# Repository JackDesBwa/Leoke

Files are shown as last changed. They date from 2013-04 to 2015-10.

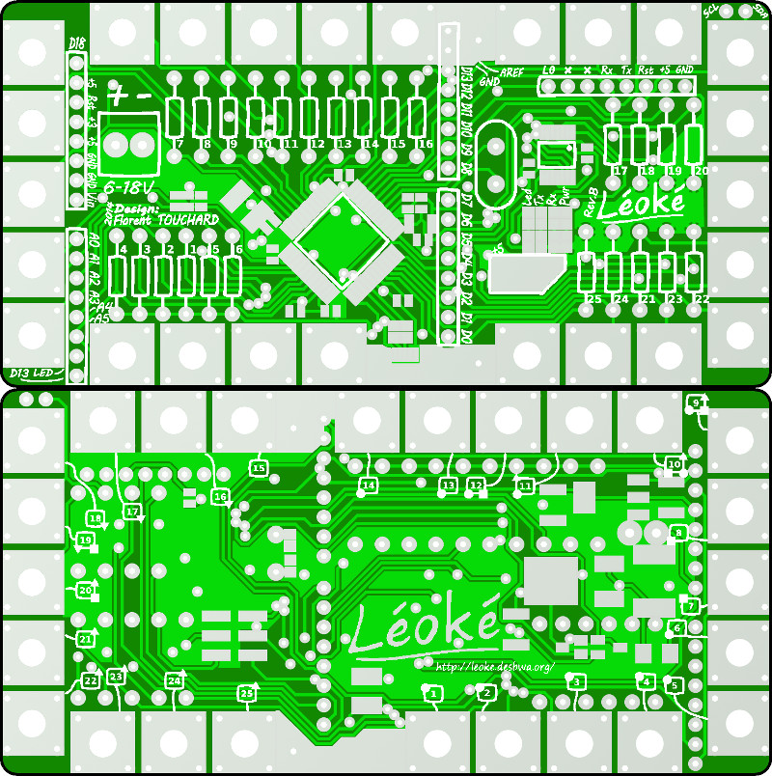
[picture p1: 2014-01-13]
webpage/carte_leoke.jpg

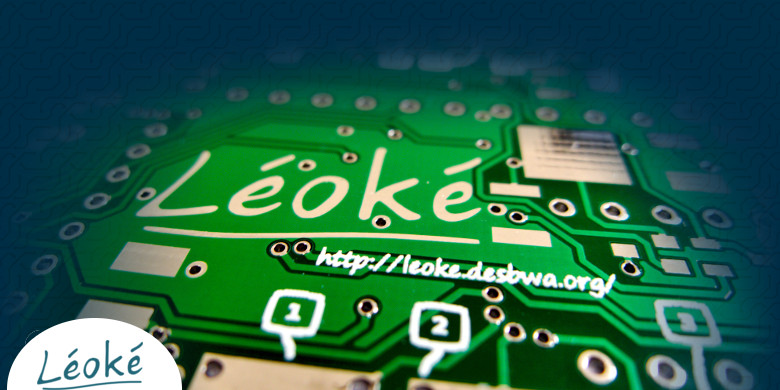
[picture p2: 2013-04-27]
webpage/head.jpg

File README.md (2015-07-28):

Léoké
=====

Please visit http://leoke.desbwa.org/ [FR] for more information.

Directory organization:

 - arduino  : Arduino-related software (Léoké Windows driver, board description & co)
 - board    : Documents about the board such as schematics or implantation
 - drawings : Miscellaneous drawings needed to make kicad files or webpage
 - gerbers  : Production files, ready to be sent to manufacturer
 - kicad    : Editable files from kicad software
 - webpage  : Files seen at above web address

Warning: This was built with arduino 1.0.6, do not know how to use it with newer versions

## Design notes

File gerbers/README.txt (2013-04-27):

leoke.gbl: Bottom coper layer
leoke.gbo: Bottom silkscreen
leoke.gbs: Bottom mask
leoke.gtl: Top copper layer
leoke.gto: Top silkscreen
leoke.gts: Top mask
leoke.drl: Drill
leoke.gko: Outline

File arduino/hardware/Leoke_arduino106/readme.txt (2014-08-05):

--------------------------------------------------------------
| Léoké Arduino Addon (based on MakeyMakey sparkfun version) |
--------------------------------------------------------------

This Arduino addon for Léoké creates an Arduino Board menu option for Léoké.

-------------------------------------------------
|         Installing the Arduino Addon          |
-------------------------------------------------

To install this addon, add "Leoke" folder into a "hardware" folder withing your Arduino sketchbook. If you don't know where your sketchbook is located, you can find it's location by going to File > Preferences within Arduino.

For Windows XP users, the sketchbook is usually located in your "My Documents/Arduino" directory. So once installed, this readme should reside in "My Documents/Arduino/hardware/Leoke". Windows 7, by default, is something like: C:\Users\<user name>\Arduino\hardware\Leoke.

Once installed, close any Arduino windows and reopen. The following board should be listed in the Tools > Board menu now:
Léoké.

-------------------------------------------------
|     Installing the Drivers (Windows only)     |
-------------------------------------------------

Windows users will need to install drivers the first time you connect Léoké. Usually a New Hardware Wizard will pop up, you'll need to direct it to the included "Drivers" folder. The driver is "Leoke.inf".

The included driver should work for Léoké with the Sparkfun VID/PID: 0x1B4F/0x2B74 (bootloader) and 0x2B75 (sketch)).

-------------------------------------------------
|            What files are included?           |
-------------------------------------------------

This addon should work with no need to modify files. If you're curious what we've done to the default Arduino files though, read on...

* bootloaders/caterina: This is a slightly modified version of the Caterina bootloader, which is used in the Arduino Leonardo. Defines were modified so the VID and PID were set to SparkFun-specific values (VID: 0x1B4F, PIDs: 0xF100/F101 [get it?!]). To compile this, you'll need to download LUFA, and point the makefile to that directory.

To compile the bootloader for Léoké, you must first set F_CPU and PID near the top of the makefile. F_CPU should be 16000000. PID should be 2B74.

This directory also includes caterina-makeymakey.hex which is the compiled images of the MaKey MaKey's bootloader. It won't be deleted after running a 'make clean'.

* cores/arduino: This is a mostly unchanged listing of all the core files required by Léoké to compile under Arduino. The files with changes are:
	USBCore.cpp: added conditional statement for seting PLLCSR.
	
* variants/leoke: This is mostly identical to the Leonardo pins_arduino.h. RX and TX macros are adapted and Léoké specific names (L1, L2...) are defined.

* boards.txt: This file is what Arduino looks at when populating its Tools > Board menu.
The "Léoké" will be added to the Tools > Board menu.

This also defines a few variables such as clock frequency, USB VID and PID, fuses, and bootloader location.

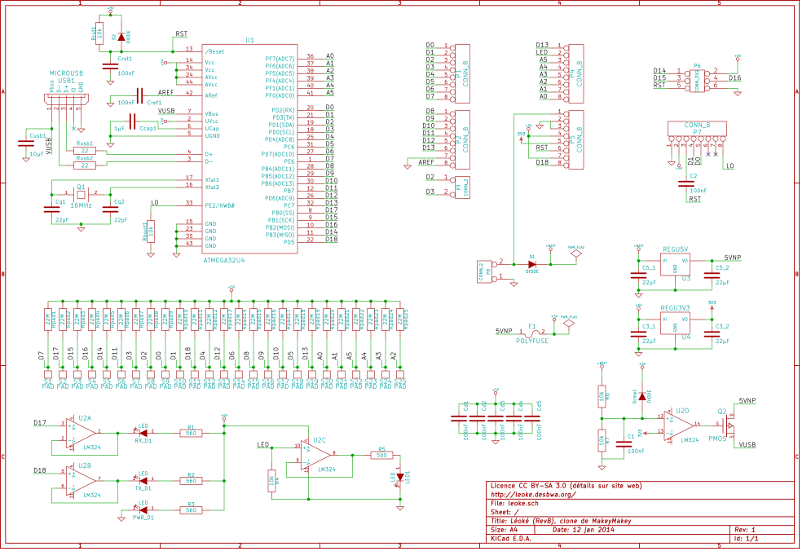
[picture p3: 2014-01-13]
webpage/schematics.png

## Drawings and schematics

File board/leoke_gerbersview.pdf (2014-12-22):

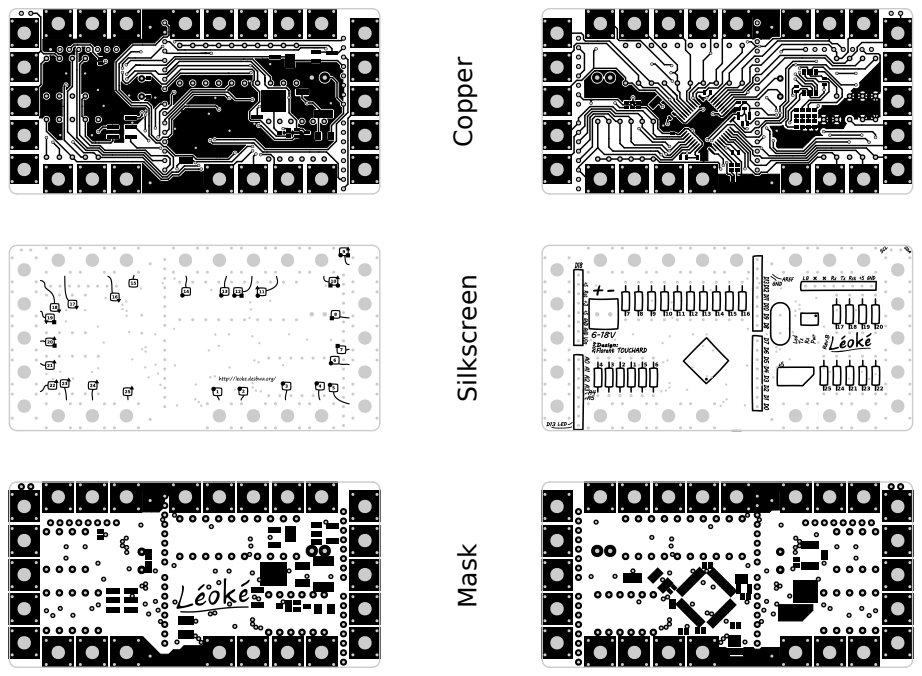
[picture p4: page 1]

Mask Silkscreen Copper

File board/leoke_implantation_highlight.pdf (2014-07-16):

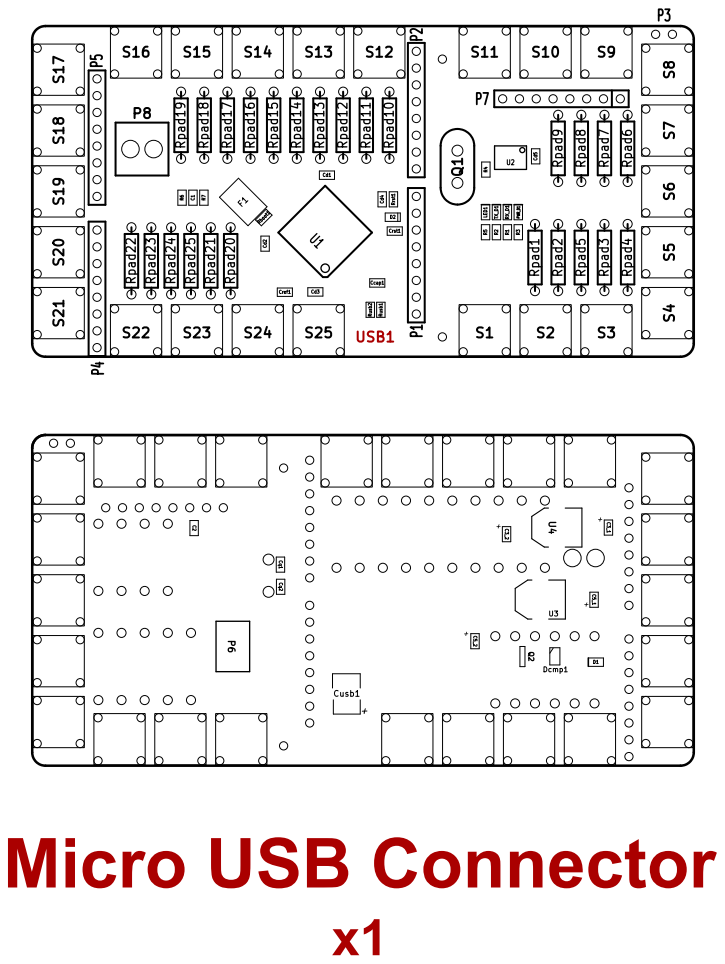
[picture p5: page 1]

Micro USB Connector

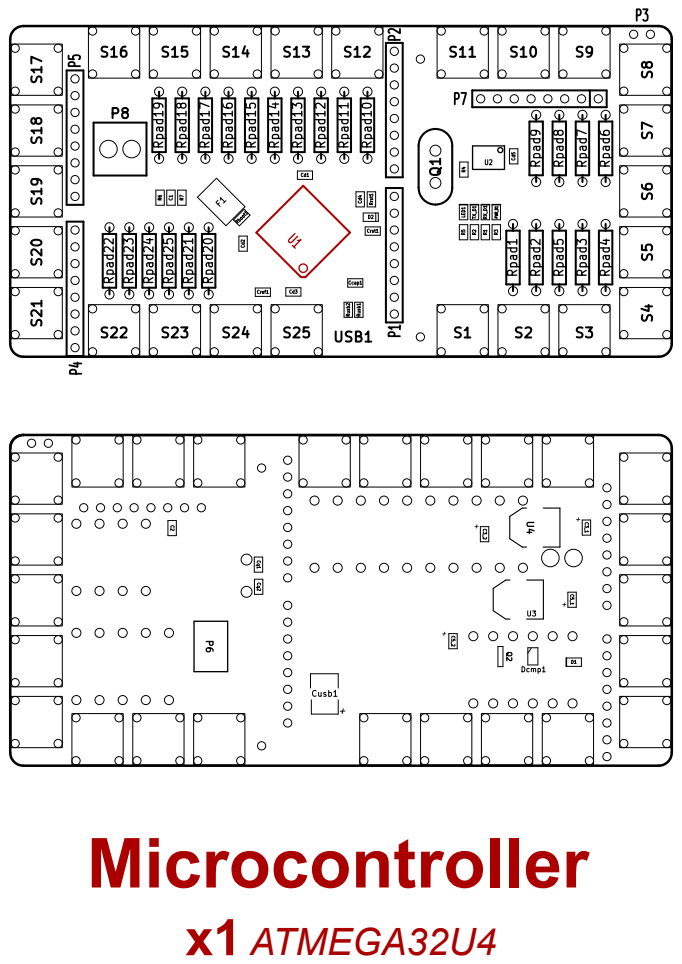
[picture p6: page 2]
Microcontroller; x1 ATMEGA32U4

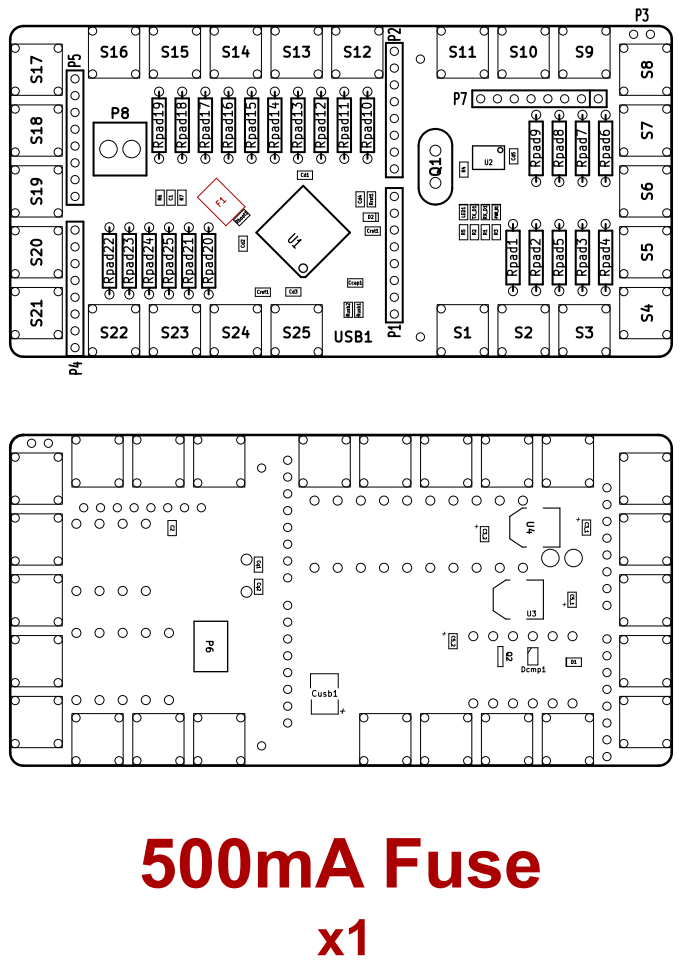
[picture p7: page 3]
500mA Fuse

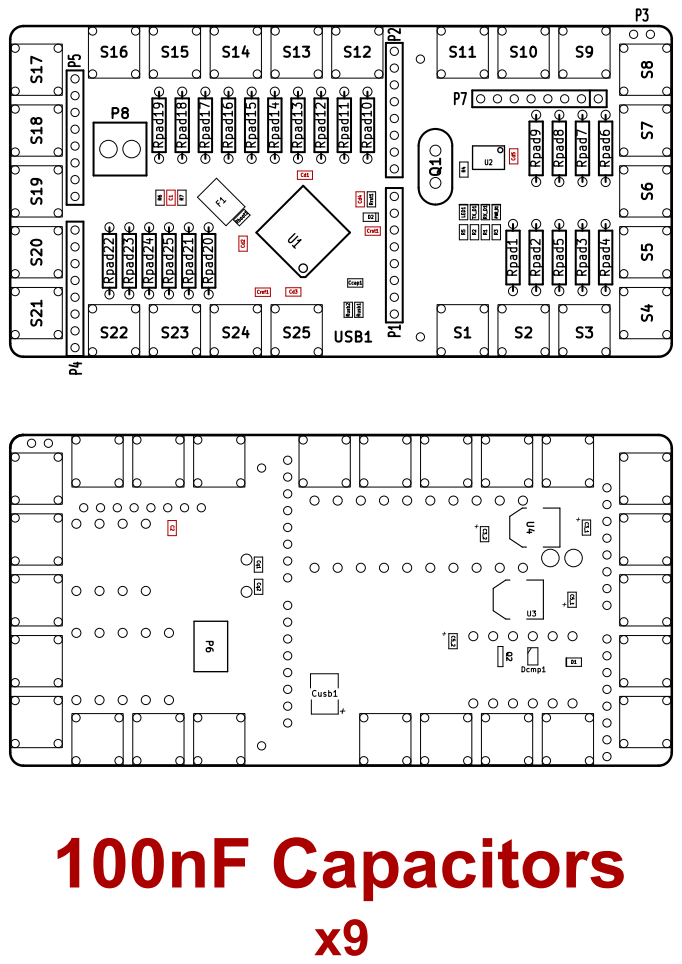
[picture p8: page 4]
100nF Capacitors

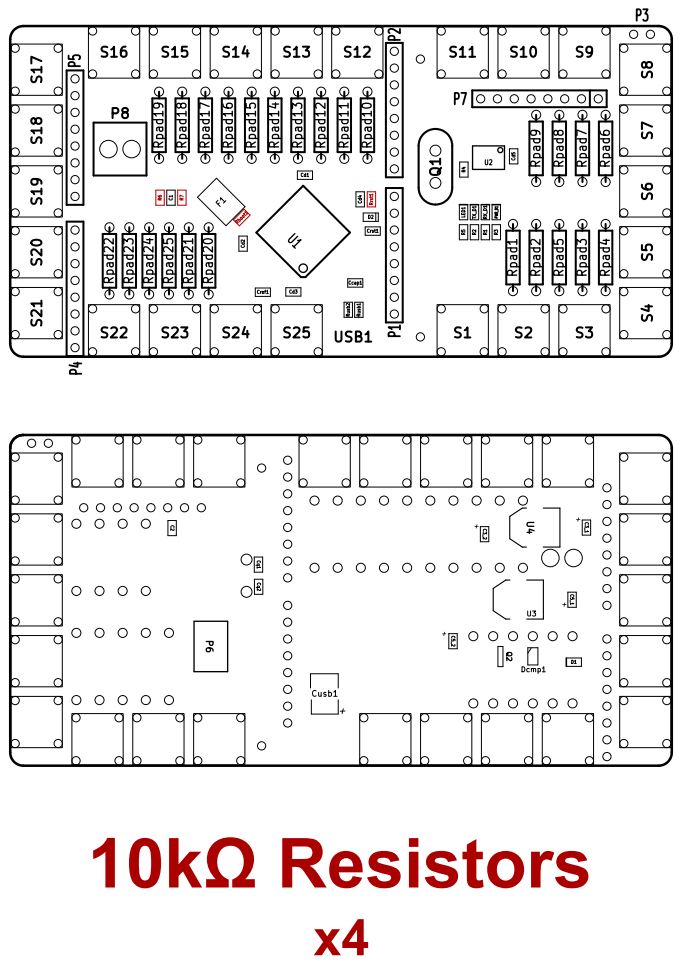
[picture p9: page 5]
10kΩ Resistors

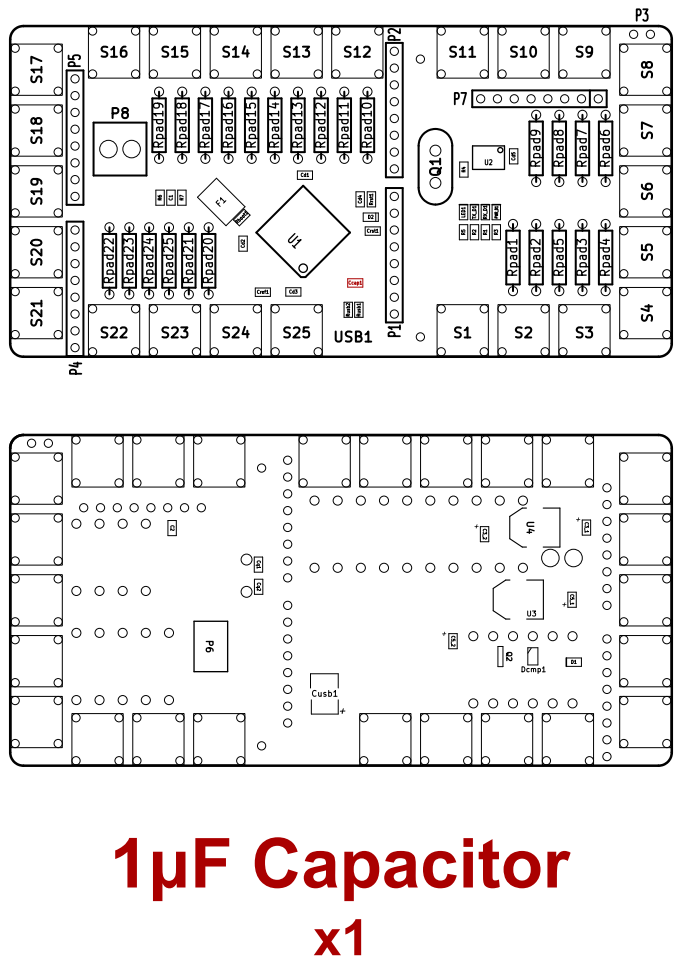
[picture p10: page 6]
1μF Capacitor

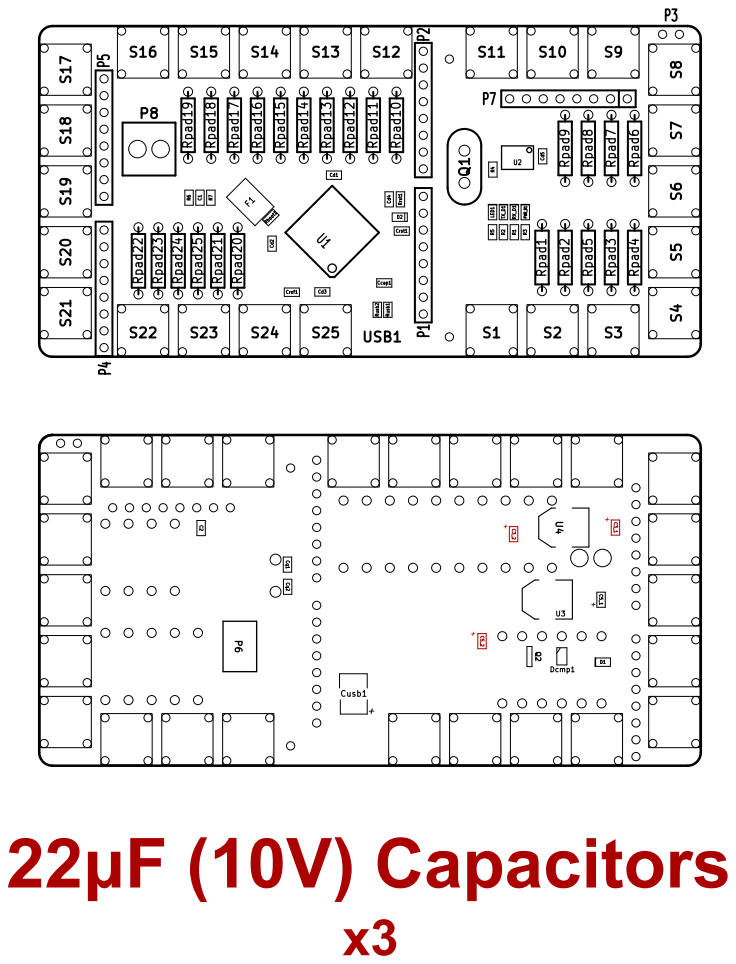
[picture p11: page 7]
22μF (10V) Capacitors

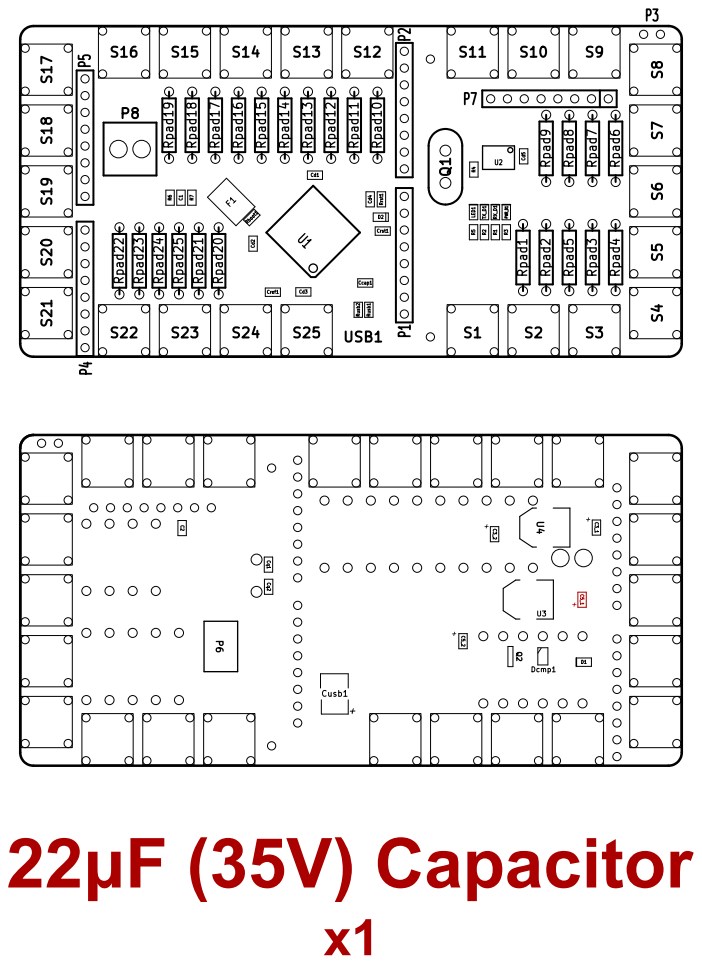
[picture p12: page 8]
22μF (35V) Capacitor

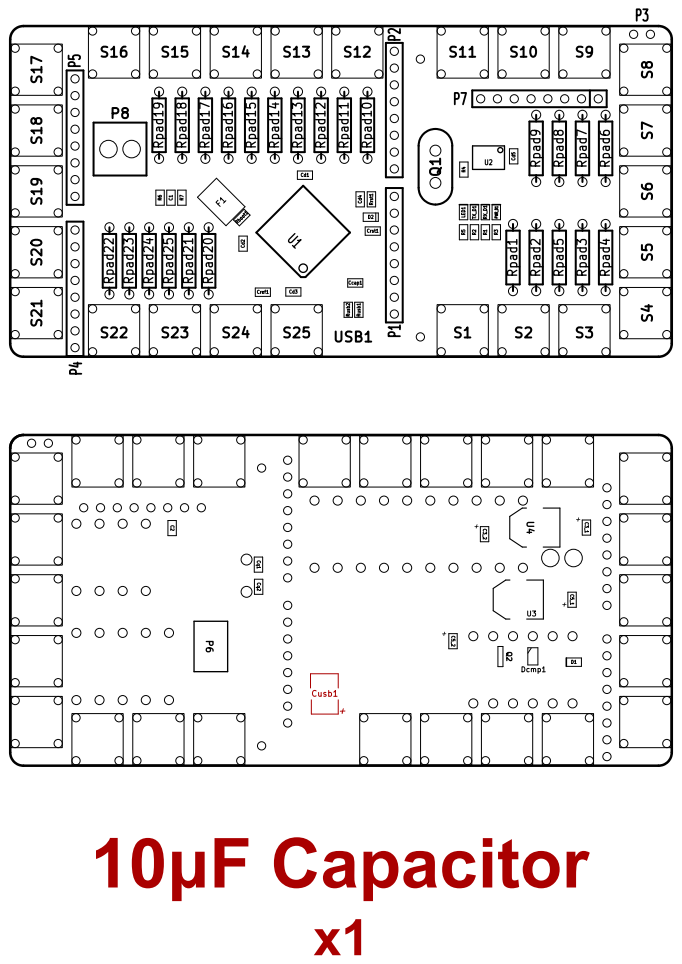
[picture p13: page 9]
10μF Capacitor

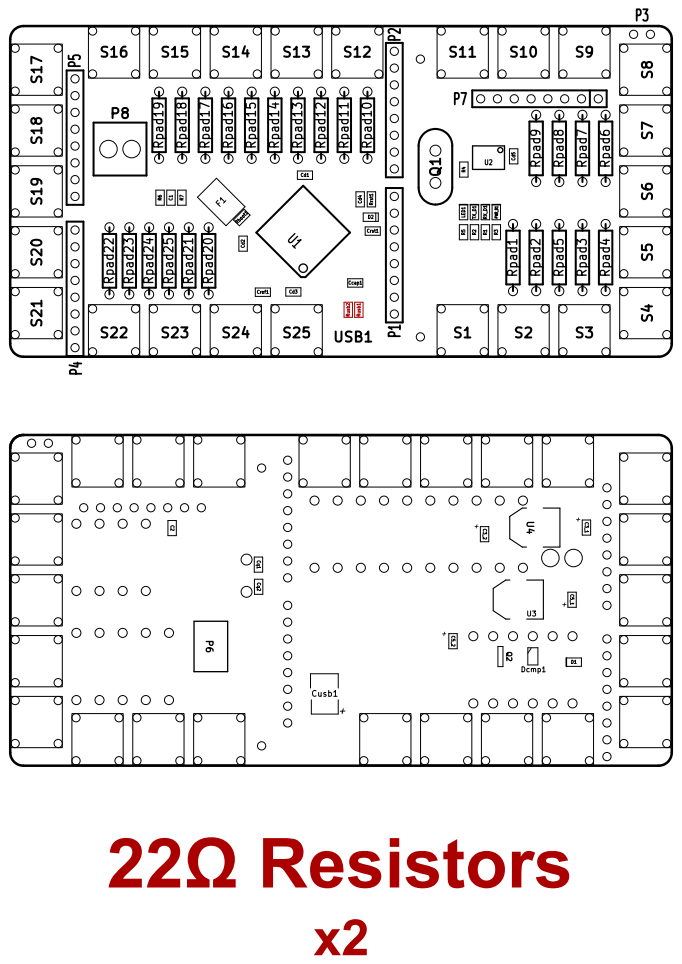
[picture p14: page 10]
22Ω Resistors

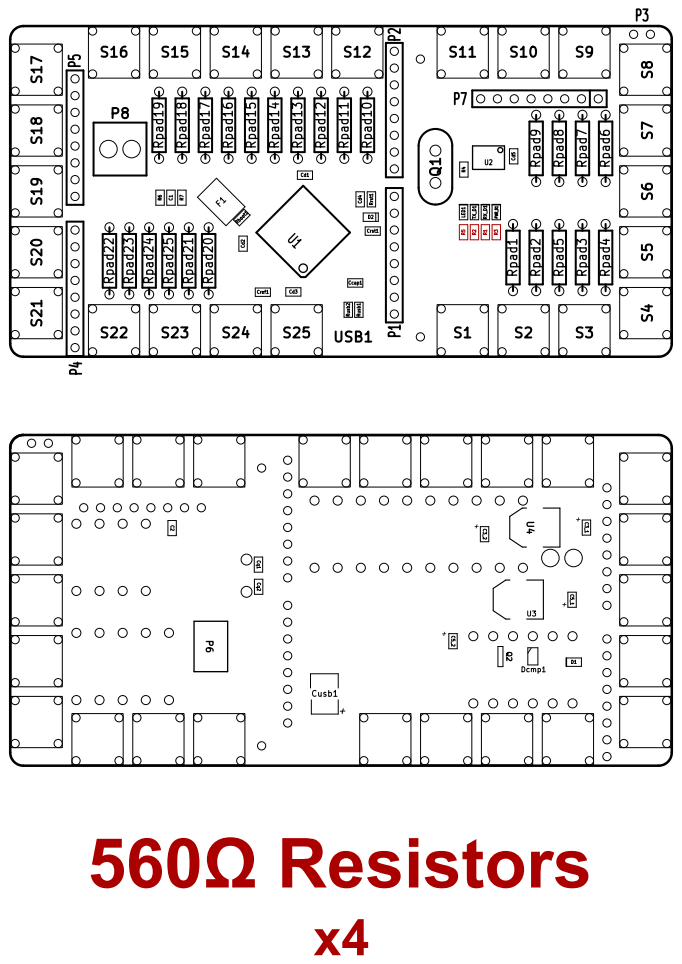
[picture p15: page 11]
560Ω Resistors

LEDs


Quad Op-amp

16MHz Quartz

22pF Capacitors

PMOS

Diodes; x3 Different references !

22MΩ Resistors

5V Regulator

3.3V Regulator

Battery terminal

Female herders; x5 8-terminals

3×2 pins header



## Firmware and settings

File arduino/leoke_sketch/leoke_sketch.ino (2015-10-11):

/*
The MIT License (MIT)
Copyright (c) 2014 JackDesBwa

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
THE SOFTWARE IS PROVIDED "AS IS", WITHOUT WARRANTY OF ANY KIND, EXPRESS OR
IMPLIED, INCLUDING BUT NOT LIMITED TO THE WARRANTIES OF MERCHANTABILITY,
FITNESS FOR A PARTICULAR PURPOSE AND NONINFRINGEMENT. IN NO EVENT SHALL THE
AUTHORS OR COPYRIGHT HOLDERS BE LIABLE FOR ANY CLAIM, DAMAGES OR OTHER
LIABILITY, WHETHER IN AN ACTION OF CONTRACT, TORT OR OTHERWISE, ARISING FROM,
OUT OF OR IN CONNECTION WITH THE SOFTWARE OR THE USE OR OTHER DEALINGS IN
THE SOFTWARE.
*/

#include <EEPROM.h> // Needed because of Arduino scrap

#include "shell.h"
#include "pads_config.h"
#include "cmds.h"

/******************************
** Data for touch and events **
******************************/

Pad pads[NBPADS];
long time;
bool shellinited = false;

/*******************
** Shell commands **
*******************/

const PROGMEM char * const motd = "\r\n\
" SHELL_COMMENT " ***************************\r\n\
" SHELL_COMMENT "  _                _\r\n\
" SHELL_COMMENT " | |     ____     | |   ____\r\n\
" SHELL_COMMENT " | |     ___  ___ | | _____\r\n\
" SHELL_COMMENT " | |    / _ \\/ _ \\| |/ / _ \\\r\n\
" SHELL_COMMENT " | |___|  __/ (_) |   <  __/\r\n\
" SHELL_COMMENT " \\_____/\\___|\\___/|_|\\_\\___|\r\n\
" SHELL_COMMENT "  http://leoke.desbwa.org/\r\n\
" SHELL_COMMENT " ***************************\r\n\
" SHELL_COMMENT "      Try help for help\r\n\
" SHELL_COMMENT " ***************************\r\n";

const ShellConf shellconfig[] = {
  {"debug", cmd_debug},
  {"eeprom", cmd_eeprom},
  {"help", cmd_help},
  {"keyboard", cmd_keyboard},
#ifdef MIDI_ENABLED
  {"midi", cmd_midi},
#endif
  {"print", cmd_print},
  {"pullup", cmd_pullup},
  {"read", cmd_read},
  {"reset", cmd_reset},
};

/********************
** Usual functions **
********************/

// Init function
void setup() {
  Serial.begin(115200);
  Keyboard.begin();
  Mouse.begin();
  time = millis();
  char * arg = "load";
  cmd_eeprom(Serial ? &Serial : 0, 1, &arg);
  for (int i = 0; i < NBPADS; ++i) {
    digitalWrite(i, LOW);
    if (pads[i].flags & PADFLAG_PULLUP_MASK)
      pinMode(i, INPUT_PULLUP);
    else
      pinMode(i, INPUT);
  }
}

// Loop function
void loop() {
  if (time < millis()) {
    for (int i = 0; i < NBPADS; ++i) {
      if ((digitalRead(i) ^ pads[i].flags) & PADFLAG_ON_MASK) {
        if (pads[i].flags & PADFLAG_DEBUG_MASK && shellinited) {
          Serial.print(SHELL_COMMENT " PAD ");
          Serial.print(i);
          Serial.print(" = ");
          Serial.println(pads[i].flags & PADFLAG_ON_MASK);
        }
        if (pads[i].flags & PADFLAG_KEYBOARD_MASK) {
          if (pads[i].flags & PADFLAG_ON_MASK)
            Keyboard.press(pads[i].key);
          else
            Keyboard.release(pads[i].key);
        }
#ifdef MIDI_ENABLED
        if (pads[i].flags & PADFLAG_MIDI_MASK) {
          MIDIUSB.note(pads[i].flags & PADFLAG_ON_MASK, pads[i].note, pads[i].octave, pads[i].channel, pads[i].velocity);
        }
#endif
        pads[i].flags ^= 1;
      }
    }
#ifdef MIDI_ENABLED
    MIDIUSB.flush();
#endif
    time = millis() + 100;
  }

  if (shellinited) {
    shell_loop();
  } else if (Serial) {
    shell_init(Serial, shellconfig, sizeof(shellconfig)/sizeof(*shellconfig), motd);
    shellinited = true;
  }
}

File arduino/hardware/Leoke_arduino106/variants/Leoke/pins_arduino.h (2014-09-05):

/*
  pins_arduino.h - Pin definition functions for Arduino
  Part of Arduino - http://www.arduino.cc/

  Copyright (c) 2007 David A. Mellis

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
  $Id: wiring.h 249 2007-02-03 16:52:51Z mellis $
*/

#ifndef Pins_Arduino_h
#define Pins_Arduino_h

#include <avr/pgmspace.h>
#define LEOKE

#define TX_RX_LED_INIT	do { } while (0) //DDRD |= (1<<5), DDRB |= (1<<0)
#define TXLED0		do { } while (0) //	PORTD |= (1<<5)
#define TXLED1		do { } while (0) //	PORTD &= ~(1<<5)
#define RXLED0		do { } while (0) //	PORTB |= (1<<0)
#define RXLED1		do { } while (0) //	PORTB &= ~(1<<0)

static const uint8_t SDA = 2;
static const uint8_t SCL = 3;

// Map SPI port to 'new' pins D14..D17
static const uint8_t SS   = 17;
static const uint8_t MOSI = 16;
static const uint8_t MISO = 14;
static const uint8_t SCK  = 15;

// Mapping of analog pins as digital I/O
// A6-A11 share with digital pins
static const uint8_t A0 = 18;
static const uint8_t A1 = 19;
static const uint8_t A2 = 20;
static const uint8_t A3 = 21;
static const uint8_t A4 = 22;
static const uint8_t A5 = 23;
static const uint8_t A6 = 24;	// D4
static const uint8_t A7 = 25;	// D6
static const uint8_t A8 = 26;	// D8
static const uint8_t A9 = 27;	// D9
static const uint8_t A10 = 28;	// D10
static const uint8_t A11 = 29;	// D12

// Leoke pins
#define L0 31
#define L1 20
#define L2 21
#define L3 22
#define L4 23
#define L5 19
#define L6 18
#define L7 13
#define L8 5
#define L9 10
#define L10 9
#define L11 8
#define L12 6
#define L13 12
#define L14 4
#define L15 30
#define L16 1
#define L17 0
#define L18 2
#define L19 3
#define L20 11
#define L21 14
#define L22 16
#define L23 15
#define L24 17
#define L25 7
static const uint8_t L[] = { L0, L1, L2, L3, L4, L5, L6, L7, L8, L9, L10, L11, L12, L13, L14, L15, L16, L17, L18, L19, L20, L21, L22, L23, L24, L25 };

#define digitalPinToPCICR(p)    ((((p) >= 8 && (p) <= 11) || ((p) >= 14 && (p) <= 17) || ((p) >= A8 && (p) <= A10)) ? (&PCICR) : ((uint8_t *)0))
#define digitalPinToPCICRbit(p) 0
#define digitalPinToPCMSK(p)    ((((p) >= 8 && (p) <= 11) || ((p) >= 14 && (p) <= 17) || ((p) >= A8 && (p) <= A10)) ? (&PCMSK0) : ((uint8_t *)0))
#define digitalPinToPCMSKbit(p) ( ((p) >= 8 && (p) <= 11) ? (p) - 4 : ((p) == 14 ? 3 : ((p) == 15 ? 1 : ((p) == 16 ? 2 : ((p) == 17 ? 0 : (p - A8 + 4))))))

//	__AVR_ATmega32U4__ has an unusual mapping of pins to channels
extern const uint8_t PROGMEM analog_pin_to_channel_PGM[];
#define analogPinToChannel(P)  ( pgm_read_byte( analog_pin_to_channel_PGM + (P) ) )

#ifdef ARDUINO_MAIN

// On the Arduino board, digital pins are also used
// for the analog output (software PWM).  Analog input
// pins are a separate set.

// ATMEL ATMEGA32U4 / ARDUINO LEONARDO
//
// D0				PD2					RXD1/INT2
// D1				PD3					TXD1/INT3
// D2				PD1		SDA			SDA/INT1
// D3#				PD0		PWM8/SCL	OC0B/SCL/INT0
// D4		A6		PD4					ADC8
// D5#				PC6		???			OC3A/#OC4A
// D6#		A7		PD7		FastPWM		#OC4D/ADC10
// D7				PE6					INT6/AIN0
//
// D8		A8		PB4					ADC11/PCINT4
// D9#		A9		PB5		PWM16		OC1A/#OC4B/ADC12/PCINT5
// D10#		A10		PB6		PWM16		OC1B/0c4B/ADC13/PCINT6
// D11#				PB7		PWM8/16		0C0A/OC1C/#RTS/PCINT7
// D12		A11		PD6					T1/#OC4D/ADC9
// D13#				PC7		PWM10		CLK0/OC4A
//
// A0		D18		PF7					ADC7
// A1		D19		PF6					ADC6
// A2		D20 	PF5					ADC5
// A3		D21 	PF4					ADC4
// A4		D22		PF1					ADC1
// A5		D23 	PF0					ADC0
//
// New pins D14..D17 to map SPI port to digital pins
//
// MISO		D14		PB3					MISO,PCINT3
// SCK		D15		PB1					SCK,PCINT1
// MOSI		D16		PB2					MOSI,PCINT2
// SS		D17		PB0					RXLED,SS/PCINT0
//
// TXLED			PD5
// RXLED		    PB0
// HWB				PE2					HWB

// these arrays map port names (e.g. port B) to the
// appropriate addresses for various functions (e.g. reading
// and writing)
const uint16_t PROGMEM port_to_mode_PGM[] = {
	NOT_A_PORT,
	NOT_A_PORT,
	(uint16_t) &DDRB,
	(uint16_t) &DDRC,
	(uint16_t) &DDRD,
	(uint16_t) &DDRE,
	(uint16_t) &DDRF,
};

const uint16_t PROGMEM port_to_output_PGM[] = {
	NOT_A_PORT,
	NOT_A_PORT,
	(uint16_t) &PORTB,
	(uint16_t) &PORTC,
	(uint16_t) &PORTD,
	(uint16_t) &PORTE,
	(uint16_t) &PORTF,
};

const uint16_t PROGMEM port_to_input_PGM[] = {
	NOT_A_PORT,
	NOT_A_PORT,
	(uint16_t) &PINB,
	(uint16_t) &PINC,
	(uint16_t) &PIND,
	(uint16_t) &PINE,
	(uint16_t) &PINF,
};

const uint8_t PROGMEM digital_pin_to_port_PGM[32] = {
	PD, // D0 - PD2
	PD,	// D1 - PD3
	PD, // D2 - PD1
	PD,	// D3 - PD0
	PD,	// D4 - PD4
	PC, // D5 - PC6
	PD, // D6 - PD7
	PE, // D7 - PE6
	
	PB, // D8 - PB4
	PB,	// D9 - PB5
	PB, // D10 - PB6
	PB,	// D11 - PB7
	PD, // D12 - PD6
	PC, // D13 - PC7
	
	PB,	// D14 - MISO - PB3
	PB,	// D15 - SCK - PB1
	PB,	// D16 - MOSI - PB2
	PB,	// D17 - SS - PB0
	
	PF,	// D18 - A0 - PF7
	PF, // D19 - A1 - PF6
	PF, // D20 - A2 - PF5
	PF, // D21 - A3 - PF4
	PF, // D22 - A4 - PF1
	PF, // D23 - A5 - PF0
	
	PD, // D24 / D4 - A6 - PD4
	PD, // D25 / D6 - A7 - PD7
	PB, // D26 / D8 - A8 - PB4
	PB, // D27 / D9 - A9 - PB5
	PB, // D28 / D10 - A10 - PB6
	PD, // D29 / D12 - A11 - PD6
	PD, // L15
	PE, // L0
};
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

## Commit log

2013-03-06 PDF schematics
2013-03-06 Schematics small error correction
    [leoke.sch]
2013-04-06 The big hardware update
    Merge of private dev branch.
    Final schematics and implantation sheet.
    Gerber production files
    Drawings sources
    Kicad EDA source files
    Webpage update
    [leoke.brd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]
2013-04-27 Hardware mod.: change protection diode topology
    Thus lot of files changed : schematics, board design file, gerbers...
    [leoke.brd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]
2013-04-27 Update webpage with PCB photos
    I just received manufactured PCB, so I change webpage design a little.
    Add PCB photos
    Change external link presentation
    Fix some HTML syntax errors
2013-12-28 Corrections in schematic and netlist (for revB)
    Rename some signals
    Set PMOS in the right direction
    Change schematic title
    Change Cusb1 value to match with USB norm
    [leoke.sch]
2013-12-28 Impact sch changes + Arduino pinout + rm drawings
    Small routing adjustments
    Correct Arduino connector spacing error
    Reroute PMOS due to schematic change
    Remove drawings for future modification
    [leoke.brd]
2014-01-12 Lots of little mods
    Move parts, add 5V area, add silks, adjust vias and routes...
    [leoke.brd]
2014-01-12 Change leds positions
    [leoke.brd, leoke.sch]
2014-01-12 Export gerber files
    [leoke.drl, leoke.gbl, leoke.gbo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]
2014-01-13 Update board/ files
2014-08-05 Add Arduino HAL directory
2014-08-21 arduino: add Midi USB device capability
2014-09-05 arduino: add note in Midi USB API
2014-09-05 arduino: add define to detect LEOKE core in sketchs
2014-09-05 arduino: first Léoké sketch (usable start point)
2014-12-22 board files: add a view of gerbers
2014-12-24 arduino hardware: use proper name for bootloader
2015-07-28 Add precision about Arduino version used
2015-08-21 arduino: add compatibility to arduino 1.6.5
2015-08-21 arduino: change midi to not write data when USB is not available
2015-08-21 arduino: update backport 1.6.5 core to 1.0.6 core
2015-08-22 website: add arduino package archive and explaination
2015-10-11 arduino: protect cmd_eeprom from nullptr stream
2015-10-11 arduino: do not wait for serial to start sketch

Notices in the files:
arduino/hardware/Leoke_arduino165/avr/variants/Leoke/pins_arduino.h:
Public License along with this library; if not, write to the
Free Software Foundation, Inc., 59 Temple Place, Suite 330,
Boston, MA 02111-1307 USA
